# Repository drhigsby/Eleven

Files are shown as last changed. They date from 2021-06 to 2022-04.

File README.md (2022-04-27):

Eleven

Eleven is an 11u wide traditionally staggered keyboard with multiple spacebar arrangements. 

* Keyboard Maintainer: [H. Bond](https://github.com/drhigsby)
* Hardware Supported: Warpstone (https://github.com/drhigsby/eleven)
* Hardware Availability: make your own/check repo files

Make example for this keyboard (after setting up your build environment):

    make eleven:default

See the [build environment setup](https://docs.qmk.fm/#/getting_started_build_tools) and the [make instructions](https://docs.qmk.fm/#/getting_started_make_guide) for more information. Brand new to QMK? Start with our [Complete Newbs Guide](https://docs.qmk.fm/#/newbs).

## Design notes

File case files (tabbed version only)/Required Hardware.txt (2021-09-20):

Required Hardware to build a Stacked Acrylic Sandwich Case for Eleven (with tabs)

4x M3 16mm bolts https://www.mcmaster.com/90353A146/ 
4x M3 25mm bolts https://www.mcmaster.com/90666A109/
8x M3 acorn cap nuts https://www.mcmaster.com/94000A330/
8x clear round bumpons; cut in half (to be placed on the underside of the PCB tabs for gasket mounting)

*These parts from McMaster-Carr are compatible, but are not the only hardware that can be used
** PM Cover and Feet in stacked case may need to be resized to 288.8mm wide

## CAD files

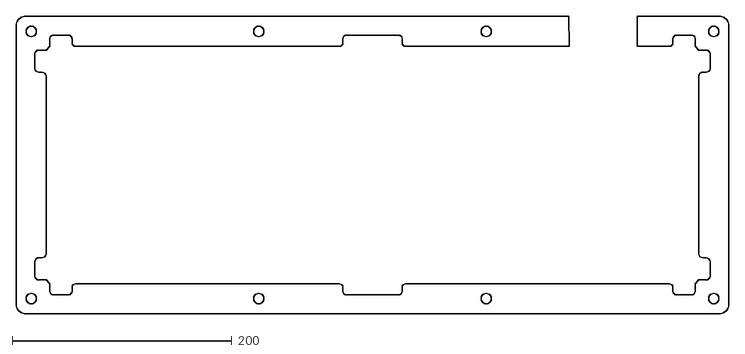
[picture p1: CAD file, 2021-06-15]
_case/sandwich/DXFs/Eleven compression layer 1x (modified).dxf
648.5 x 270.5

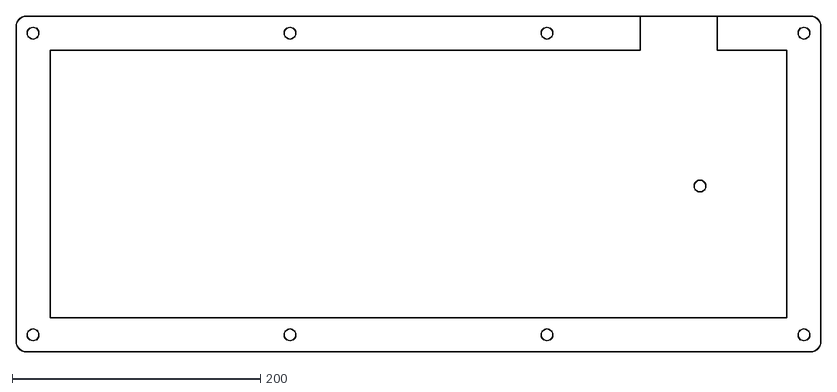
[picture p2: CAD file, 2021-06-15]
_case/sandwich/SVGs/Eleven sandwich bottom for modifying .dxf
648.5 x 270.5

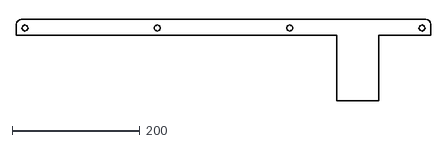
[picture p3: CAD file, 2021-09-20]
case files (tabbed version only)/DXFs/Eleven SAS PM Cover1.dxf
648.5 x 127.5

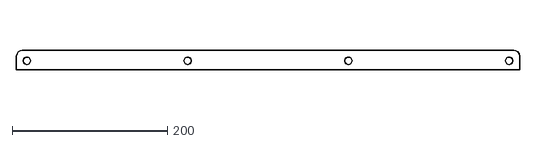
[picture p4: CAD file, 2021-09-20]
case files (tabbed version only)/DXFs/Eleven SAS PM Foot 1x or 2x.dxf
648.5 x 25.4

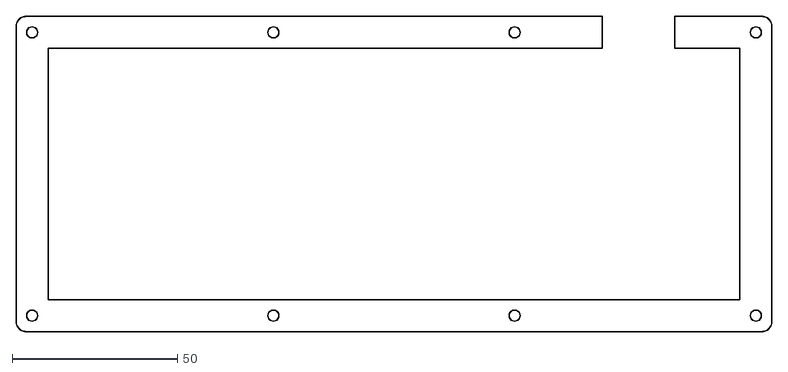
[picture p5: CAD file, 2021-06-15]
case files (tabbed version only)/DXFs/Eleven SAS open layer layer 1x.dxf
228.8 x 95.4

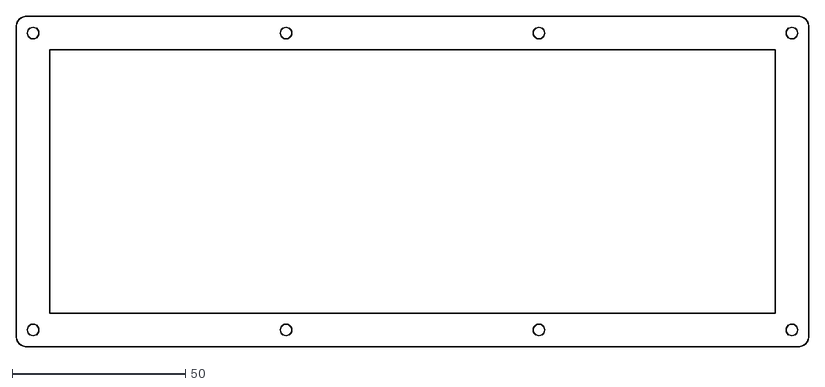
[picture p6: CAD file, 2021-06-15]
case files (tabbed version only)/DXFs/Eleven SAS top layer 2x.dxf
228.8 x 95.4

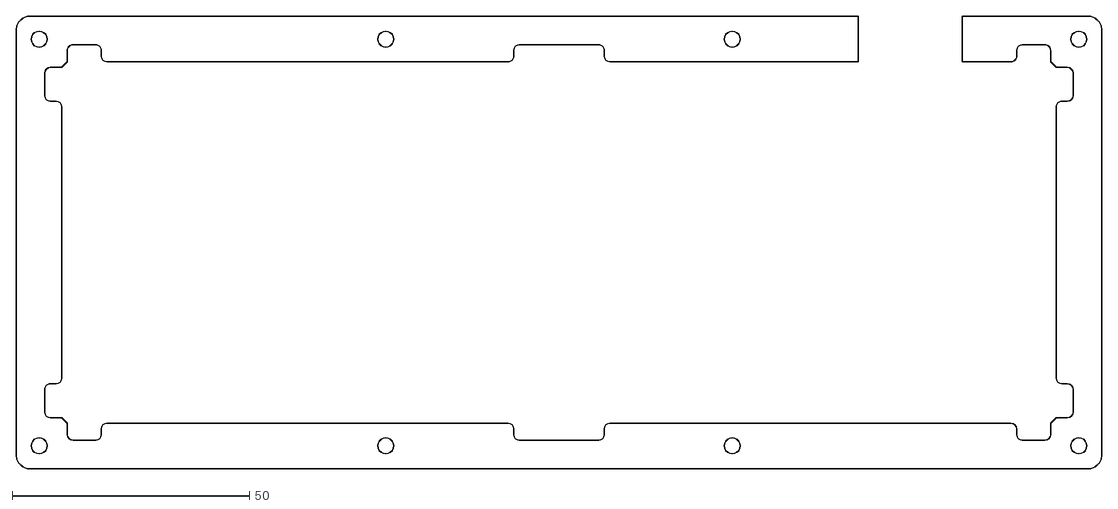
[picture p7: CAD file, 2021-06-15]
case files (tabbed version only)/DXFs/Eleven SAS compression layer 1x.dxf
228.8 x 95.4

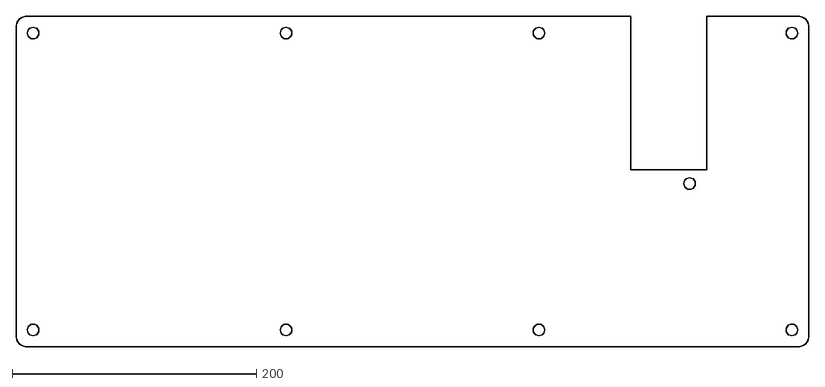
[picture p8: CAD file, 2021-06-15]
case files (tabbed version only)/DXFs/Eleven SAS bottom layer 1x.dxf
648.5 x 270.5

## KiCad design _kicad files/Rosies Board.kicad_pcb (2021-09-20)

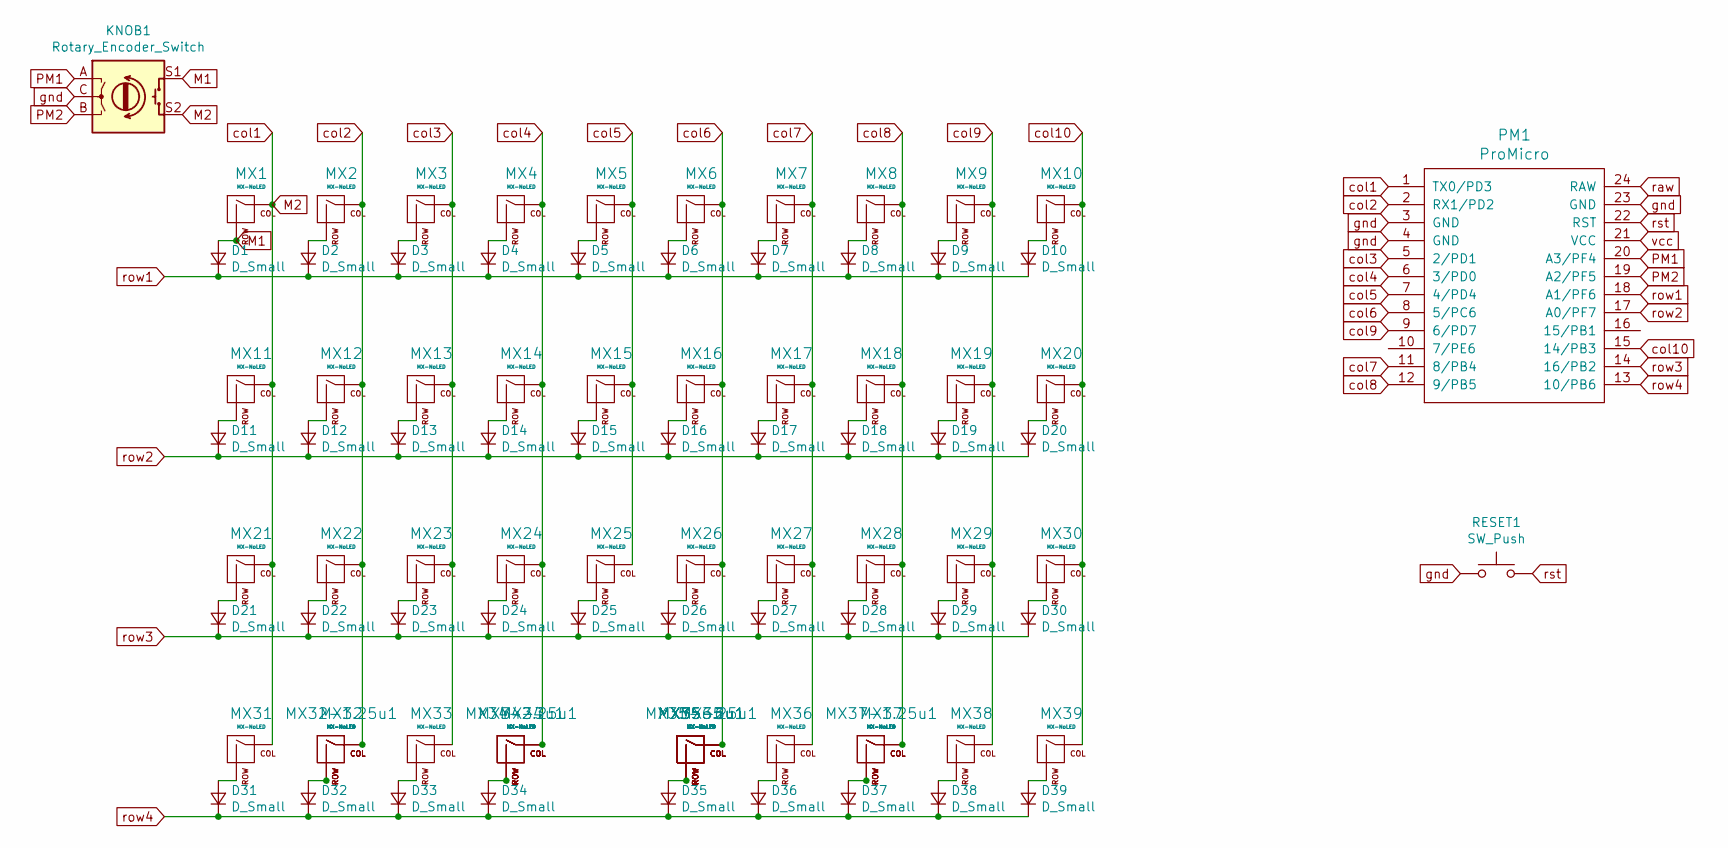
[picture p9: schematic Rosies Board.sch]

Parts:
D1, D2, D3, D4, D5, D6, D7, D8, D9, D10, D11, D12, D13, D14, D15, D16, D17, D18, D19, D20, D21, D22, D23, D24, D25, D26, D27, D28, D29, D30, D31, D32, D33, D34, D35, D36, D37, D38, D39: D_Small; Diode-Hybrid-Back
KNOB1: Rotary_Encoder_Switch; RotaryEncoder_Alps_EC11E-Switch_Vertical_H20mm_CircularMoun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
MX1, MX2, MX3, MX4, MX5, MX6, MX7, MX8, MX9, MX10, MX12, MX13, MX14, MX15, MX16, MX17, MX18, MX19, MX22, MX23, MX24, MX25, MX26, MX27, MX28, MX29, MX32, MX33, MX37, MX39: MX-NoLED; MXOnly-1U-NoLED
MX11, MX30, MX31, MX32-1.25u1, MX36, MX37-1.25u1, MX38: MX-NoLED; MXOnly-1.25U-NoLED
MX20, MX21: MX-NoLED; MXOnly-1.75U-NoLED
MX34, MX35-2u1: MX-NoLED; MXOnly-2U-ReversedStabilizers-NoLED
MX34-2.25u1, MX35: MX-NoLED; MXOnly-2.25U-ReversedStabilizers-NoLED
MX34-3u1, MX35-3u1: MX-NoLED; MXOnly-3U-ReversedStabilizers-NoLED
MX35-6.25u1: MX-NoLED; MXOnly-6.25U-ReversedStabilizers-NoLED
MX35-6u1: MX-NoLED; MXOnly-6U-Centered-ReversedStabilizers-NoLED
PM1: ProMicro; ArduinoProMicro
RESET1: SW_Push; SKQG-1155865

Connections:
M1: D1.2 (A), KNOB1.S1, MX1.2 (ROW)
M2: KNOB1.S2, MX1.1 (COL), MX11.1 (COL), MX21.1 (COL), MX31.1 (COL), PM1.1 (TX0/PD3)
unnamed: D2.2 (A), MX2.2 (ROW)
unnamed: D3.2 (A), MX3.2 (ROW)
unnamed: D4.2 (A), MX4.2 (ROW)
unnamed: D5.2 (A), MX5.2 (ROW)
unnamed: D6.2 (A), MX6.2 (ROW)
unnamed: D7.2 (A), MX7.2 (ROW)
unnamed: D8.2 (A), MX8.2 (ROW)
unnamed: D9.2 (A), MX9.2 (ROW)
unnamed: D10.2 (A), MX10.2 (ROW)
unnamed: D11.2 (A), MX11.2 (ROW)
unnamed: D12.2 (A), MX12.2 (ROW)
unnamed: D13.2 (A), MX13.2 (ROW)
unnamed: D14.2 (A), MX14.2 (ROW)
unnamed: D15.2 (A), MX15.2 (ROW)
unnamed: D16.2 (A), MX16.2 (ROW)
unnamed: D17.2 (A), MX17.2 (ROW)
unnamed: D18.2 (A), MX18.2 (ROW)
unnamed: D19.2 (A), MX19.2 (ROW)
unnamed: D20.2 (A), MX20.2 (ROW)
unnamed: D21.2 (A), MX21.2 (ROW)
unnamed: D22.2 (A), MX22.2 (ROW)
unnamed: D23.2 (A), MX23.2 (ROW)
unnamed: D24.2 (A), MX24.2 (ROW)
unnamed: D25.2 (A), MX25.2 (ROW)
unnamed: D26.2 (A), MX26.2 (ROW)
unnamed: D27.2 (A), MX27.2 (ROW)
unnamed: D28.2 (A), MX28.2 (ROW)
unnamed: D29.2 (A), MX29.2 (ROW)
unnamed: D30.2 (A), MX30.2 (ROW)
unnamed: D31.2 (A), MX31.2 (ROW)
unnamed: D32.2 (A), MX32.2 (ROW), MX32-1.25u1.2 (ROW)
unnamed: D33.2 (A), MX33.2 (ROW)
unnamed: D34.2 (A), MX34.2 (ROW), MX34-2.25u1.2 (ROW), MX34-3u1.2 (ROW)
unnamed: D35.2 (A), MX35.2 (ROW), MX35-2u1.2 (ROW), MX35-3u1.2 (ROW), MX35-6.25u1.2 (ROW), MX35-6u1.2 (ROW)
unnamed: D36.2 (A), MX36.2 (ROW)
unnamed: D37.2 (A), MX37.2 (ROW), MX37-1.25u1.2 (ROW)
unnamed: D38.2 (A), MX38.2 (ROW)
unnamed: D39.2 (A), MX39.2 (ROW)
PM1: KNOB1.A, PM1.20 (A3/PF4)
PM2: KNOB1.B, PM1.19 (A2/PF5)
col2: MX2.1 (COL), MX12.1 (COL), MX22.1 (COL), MX32.1 (COL), MX32-1.25u1.1 (COL), PM1.2 (RX1/PD2)
col3: MX3.1 (COL), MX13.1 (COL), MX23.1 (COL), MX33.1 (COL), PM1.5 (2/PD1)
col4: MX4.1 (COL), MX14.1 (COL), MX24.1 (COL), MX34.1 (COL), MX34-2.25u1.1 (COL), MX34-3u1.1 (COL), PM1.6 (3/PD0)
col5: MX5.1 (COL), MX15.1 (COL), MX25.1 (COL), PM1.7 (4/PD4)
col6: MX6.1 (COL), MX16.1 (COL), MX26.1 (COL), MX35.1 (COL), MX35-2u1.1 (COL), MX35-3u1.1 (COL), MX35-6.25u1.1 (COL), MX35-6u1.1 (COL), PM1.8 (5/PC6)
col7: MX7.1 (COL), MX17.1 (COL), MX27.1 (COL), MX36.1 (COL), PM1.11 (8/PB4)
col8: MX8.1 (COL), MX18.1 (COL), MX28.1 (COL), MX37.1 (COL), MX37-1.25u1.1 (COL), PM1.12 (9/PB5)
col9: MX9.1 (COL), MX19.1 (COL), MX29.1 (COL), MX38.1 (COL), PM1.9 (6/PD7)
col10: MX10.1 (COL), MX20.1 (COL), MX30.1 (COL), MX39.1 (COL), PM1.15 (14/PB3)
gnd: KNOB1.C, PM1.3 (GND), PM1.4 (GND), PM1.23 (GND), RESET1.1
raw: PM1.24 (RAW)
row1: D1.1 (K), D2.1 (K), D3.1 (K), D4.1 (K), D5.1 (K), D6.1 (K), D7.1 (K), D8.1 (K), D9.1 (K), D10.1 (K), PM1.18 (A1/PF6)
row2: D11.1 (K), D12.1 (K), D13.1 (K), D14.1 (K), D15.1 (K), D16.1 (K), D17.1 (K), D18.1 (K), D19.1 (K), D20.1 (K), PM1.17 (A0/PF7)
row3: D21.1 (K), D22.1 (K), D23.1 (K), D24.1 (K), D25.1 (K), D26.1 (K), D27.1 (K), D28.1 (K), D29.1 (K), D30.1 (K), PM1.14 (16/PB2)
row4: D31.1 (K), D32.1 (K), D33.1 (K), D34.1 (K), D35.1 (K), D36.1 (K), D37.1 (K), D38.1 (K), D39.1 (K), PM1.13 (10/PB6)
rst: PM1.22 (RST), RESET1.2
vcc: PM1.21 (VCC)

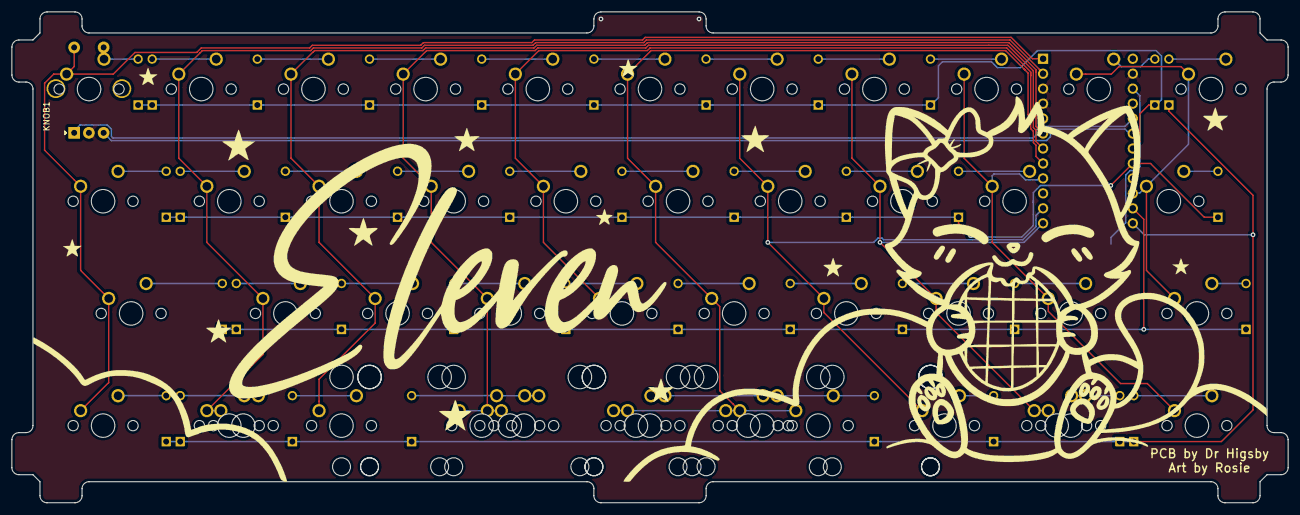
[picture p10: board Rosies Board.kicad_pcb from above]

Board: 2 copper layers, 216.7 x 83.3 mm, 89 parts (1 on the bottom side), 57 nets.

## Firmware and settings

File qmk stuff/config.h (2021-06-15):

/* Copyright 2021 drhigsby
 *
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
 * You should have received a copy of the GNU General Public License
 * along with this program.  If not, see <http://www.gnu.org/licenses/>.
 */

#pragma once

#include "config_common.h"

#define MANUFACTURER DrHigsby
#define PRODUCT Eleven
#define VENDOR_ID 0x0420
#define PRODUCT_ID 0xA421
#define DEVICE_VER 0xA420

/* key matrix size */
#define MATRIX_ROWS 4
#define MATRIX_COLS 10

/* Define encoder pads */
#define ENCODERS_PAD_A { F4 }
#define ENCODERS_PAD_B { F5 }

/* key matrix pins */
#define MATRIX_ROW_PINS { F6, F7, B2, B6}
#define MATRIX_COL_PINS { D3, D2, D1, D0, D4, C6, B4, B5, D7, B3}
#define UNUSED_PINS

/* COL2ROW or ROW2COL */
#define DIODE_DIRECTION COL2ROW

/* Mechanical locking support. Use KC_LCAP, KC_LNUM or KC_LSCR instead in keymap */
#define LOCKING_SUPPORT_ENABLE
/* Locking resynchronize hack */
#define LOCKING_RESYNC_ENABLE

/* Debounce reduces chatter (unintended double-presses) - set 0 if debouncing is not needed */
#define DEBOUNCE 5

#define COMBO_COUNT 8

#define COMBO_TERM 45

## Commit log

2021-02-23 update silks
    [Rosies Board-B_Cu.gbr, Rosies Board-B_Mask.gbr, Rosies Board-B_Paste.gbr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]
2021-06-15 eleven with tabs update
    [##Eleven sandwich bottom for modifying .dxf, #Eleven compression layer 1x (modified).dxf, #Eleven sandwich bottom 1x.dxf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]
2021-06-15 repo cleanup
    [##Eleven sandwich bottom for modifying .dxf, #Eleven compression layer 1x (modified).dxf, #Eleven sandwich bottom 1x.dxf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]
2021-06-15 further cleanup
    [Eleven SAS bottom layer 1x.dxf, Eleven SAS compression layer 1x.dxf, Eleven SAS open layer layer 1x.dxf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]
2021-06-15 removing useless subfolder
    [Eleven SAS bottom layer 1x.dxf, Eleven SAS compression layer 1x.dxf, Eleven SAS open layer layer 1x.dxf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]
2021-09-20 updating kicad related things
    [Rosies Board.kicad_pcb]
2021-09-20 added PM cover/feet & updated case readme
    [Eleven SAS PM Cover1.dxf, Eleven SAS PM Foot 1x or 2x.dxf]
2021-09-20 updated case readme

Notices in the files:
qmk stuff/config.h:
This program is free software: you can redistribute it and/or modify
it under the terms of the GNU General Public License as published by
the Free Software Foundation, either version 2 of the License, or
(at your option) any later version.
